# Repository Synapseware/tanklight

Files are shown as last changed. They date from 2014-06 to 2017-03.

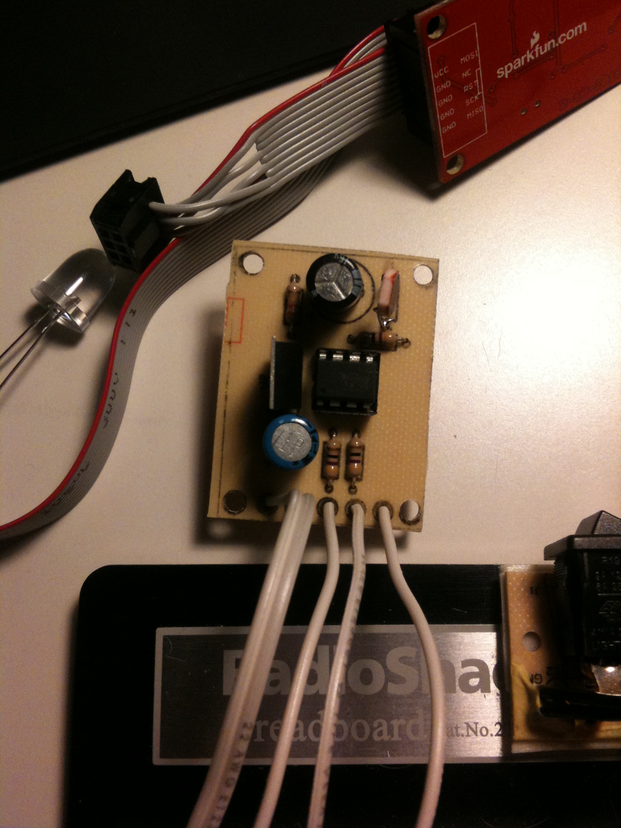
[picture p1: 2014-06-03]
media/IMG_3B10C66F-7ECF-4C1E-85A0-E6A24B57A7C3.JPG

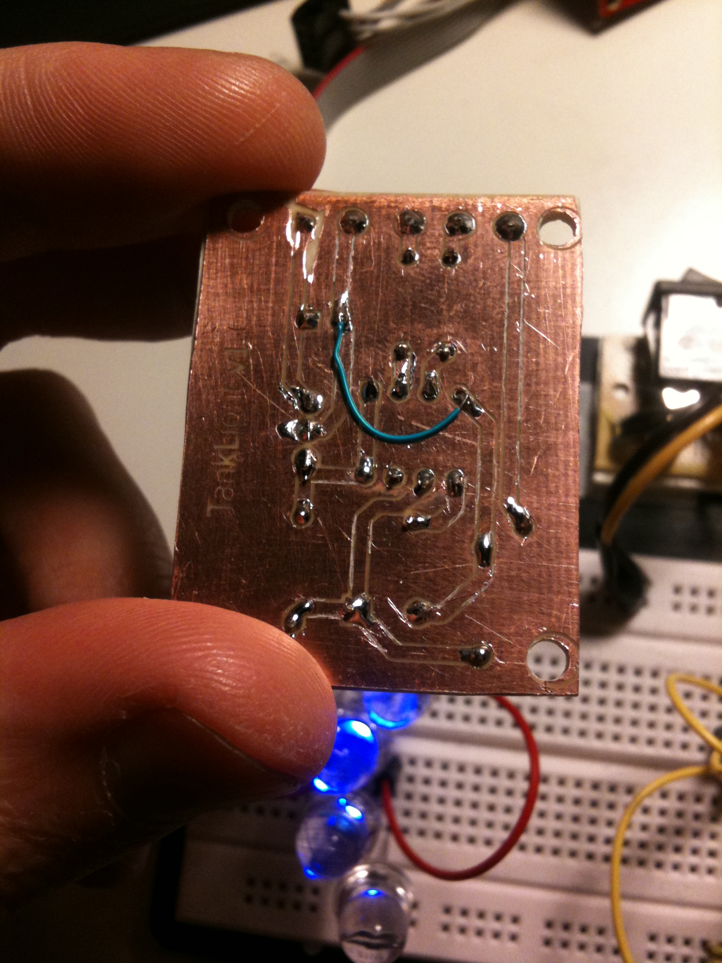
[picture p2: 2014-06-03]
media/IMG_438924C5-C81B-45E8-9A56-AECAA56EA485.JPG

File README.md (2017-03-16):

tanklights
==========

Tanklights is a fun project for adding moonlight lighting effects to a fish tank, or other environment where having an undulating lighting effect is desirable.  When properly laid out, the lighting is meant to be a rough simulation of what moonlight might look like under water.

The hardware/LEDs are wired up in a charlieplexed format.  Using just 3 pins of the micro controller (an Atmel ATTiny13), 6 LEDs can be individually controller.

The formula for the total number of LEDs is given by n^2-n, where n is the number of pins.  So, 3^2-3 = 6.

Read more about charlieplexing here: https://en.wikipedia.org/wiki/Charlieplexing

The lighting effects are accomplished by very fast switching of the LED matrix, so that persistence of vision plays a key role in the apparent light levels of the LEDs.

## building
The project has a simple Makefile.  It is currently configured to compiled under Linux only (but could be easily modified for other operating systems).  You will need to install AVRA, which is the open source equivalent of the Atmel AVR Assembler, avrasm.exe, that is included with AVR Studio for Windows.

### AVRA
Avra can also be installed easily on Linux:  `apt install -y avra` for Debian based systems.  The AVRA project home is here: http://avra.sourceforge.net/

### Atmel AVR Assembler
http://www.atmel.com/webdoc/avrassembler/index.html

### Other notes
The main idea with this project is not to build yet another LED blinking hello-world type of application, but is more a demonstration of what you can build using assembly and very lower powered micro-controllers.  Current code size is 640 bytes, or 320 words.  The timers on the ATTiny13 are used to advance or cycle through the lighting pattern, while the main charlieplexing display driver code is left to run at full speed.

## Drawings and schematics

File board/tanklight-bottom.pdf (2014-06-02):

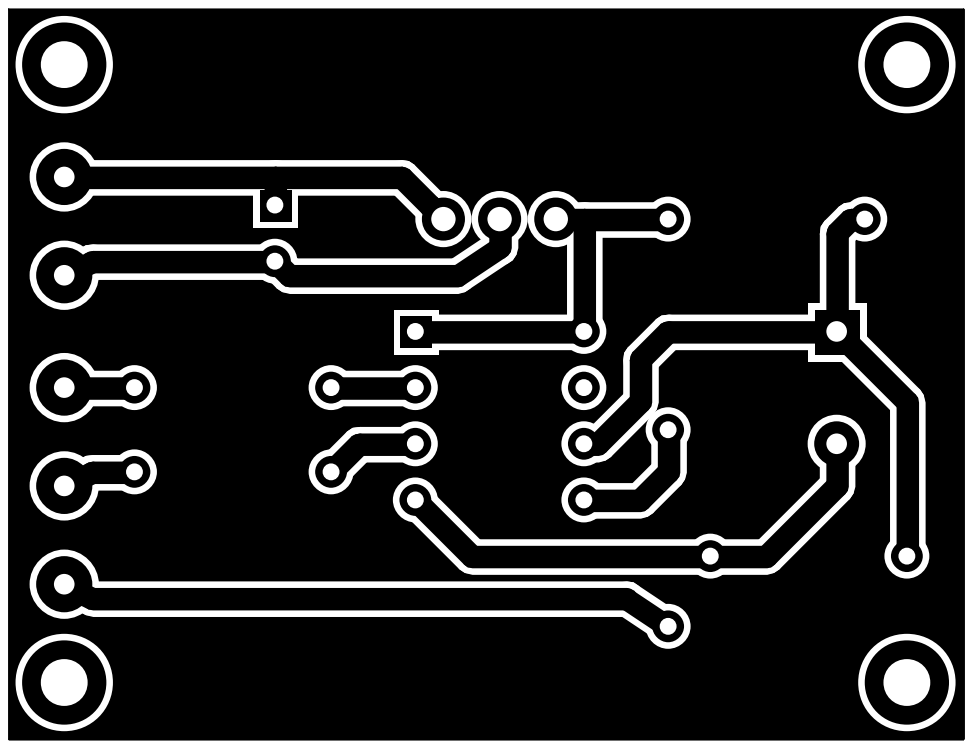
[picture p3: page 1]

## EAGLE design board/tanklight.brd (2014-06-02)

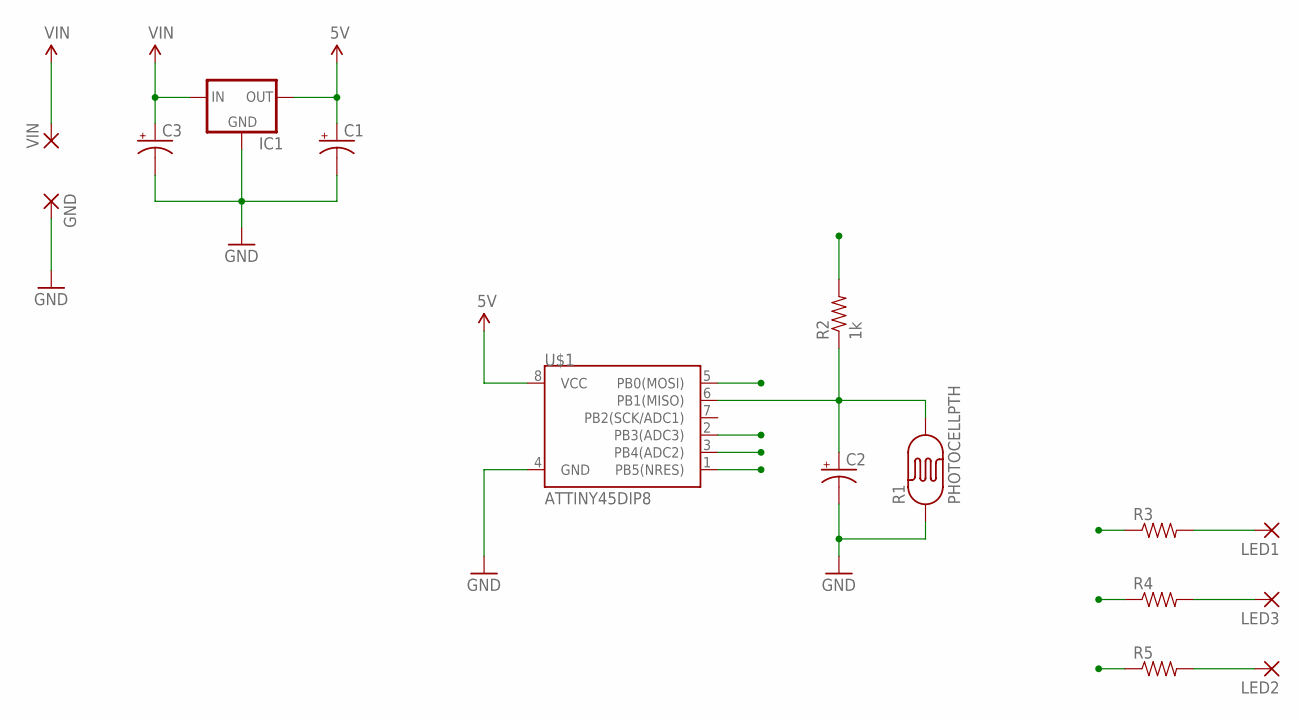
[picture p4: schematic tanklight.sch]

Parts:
C1, C3: CAP_POLPTH2; CPOL-RADIAL-10UF-25V
C2: CAP_POLPTH1; CPOL-RADIAL-100UF-25V
GND: 2,54/1,0
IC1: V_REG_78XXSINK; TO220-IGO
LED1, LED2, LED3: 2,54/1,0
R1: PHOTOCELLPTH; PHOTOCELL
R2: 1k; AXIAL-0.4
R3, R4, R5: RESISTORPTH-1/4W; AXIAL-0.4
U$1: ATTINY45DIP8; DIP08
VIN: 2,54/1,0

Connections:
5V: C1.1 (+), IC1.OUT, R2.P$2 (2), U$1.1 (PB5(NRES)), U$1.8 (VCC)
GND: C1.2 (-), C2.2 (-), C3.2 (-), GND.1, IC1.GND, R1.1, U$1.4 (GND)
LED1: R3.P$1 (1), U$1.5 (PB0(MOSI))
LED2: R5.P$1 (1), U$1.3 (PB4(ADC2))
LED3: R4.P$1 (1), U$1.2 (PB3(ADC3))
unnamed: C2.1 (+), R1.2, R2.P$1 (1), U$1.6 (PB1(MISO))
unnamed: LED1.1, R3.P$2 (2)
unnamed: LED3.1, R4.P$2 (2)
unnamed: LED2.1, R5.P$2 (2)
VIN: C3.1 (+), IC1.IN, VIN.1

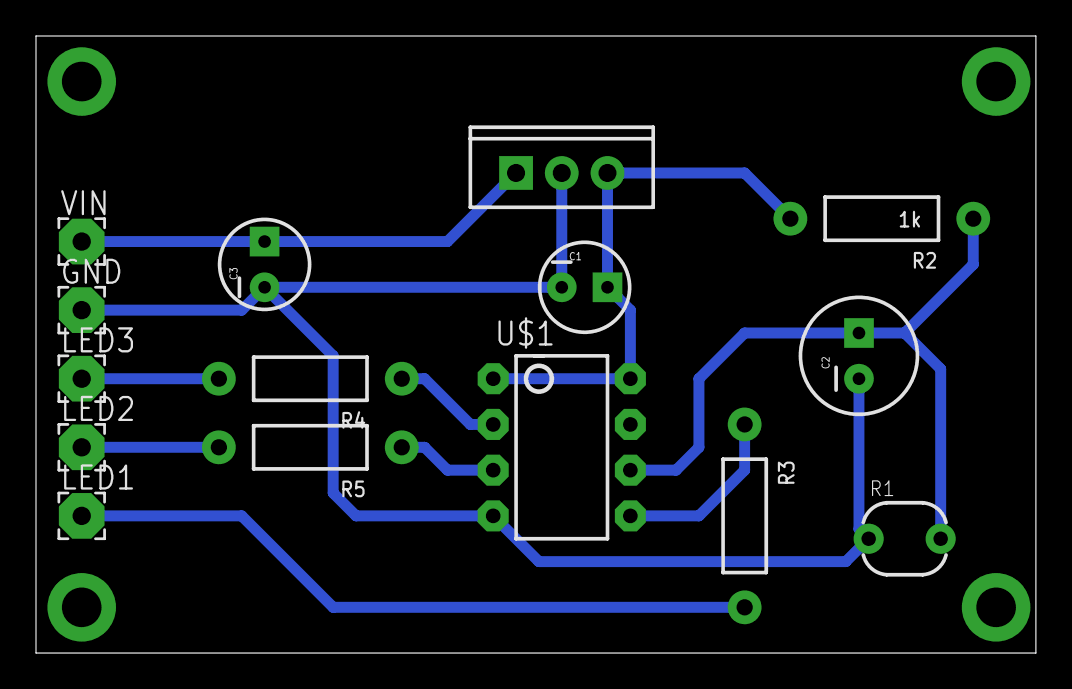
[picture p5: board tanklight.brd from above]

Board: 2 copper layers, 55.5 x 34.3 mm, 15 parts (0 on the bottom side), 10 nets.

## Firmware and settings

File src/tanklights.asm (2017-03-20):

;
; ********************************************
; Tank Light Project
; Drives 6 LEDs in a PWM/charlieplexed setup
; for gentle undulating night light.
; A photoresistor is connected across ANI1,
; so the light effect only runs when it's
; dark in the room.
; (C)2011 by Matthew Potter
; ********************************************

; Included header file for target AVR type
.NOLIST
.INCLUDE "tn13def.inc" ; Header for ATTINY13
.LIST
;
;
; ================================================================================================
;   R E G I S T E R   D E F I N I T I O N S
; ================================================================================================
.DEF	rmp				= r16
.DEF	rtmp			= r17
.DEF	rPWM_POS		= r18
.DEF	rACTIVE_LED		= r19
.DEF	rOFFSET			= r20
.DEF	rDELAY			= r21


; ================================================================================================
;	C O N S T A N T S
; ================================================================================================

; scan code status values
.EQU	PRIMARY_DELAY	= 180
.EQU	FIXED_DELAY		= 0
.EQU    TOTAL_CHANNELS  = 6
.EQU    LIGHT_TABLE_LEN = 252
.EQU    OFFSET_MULTIPLE = 42
.EQU	LED_PORT_MASK	= 0b11100110


; ================================================================================================
;	D A T A  S E G M E N T
; ================================================================================================
.DSEG
	on_values:	.BYTE	TOTAL_CHANNELS


; ================================================================================================
;   R E S E T   A N D   I N T   V E C T O R S
; ================================================================================================
;
.CSEG
.ORG $0000
	rjmp	Main ; Int vector 1 - Reset vector
	reti	; Int vector 2
	reti	; Int vector 3
	reti	; Int vector 4
	reti	; Int vector 5
	rjmp	ISR_AnalogComp_Handler ; Int vector 6
	rjmp	ISR_Timer0_CompareAHandler; Int vector 7
	reti	; Int vector 8
	reti	; Int vector 9
	reti	; Int vector 10


; ================================================================================================
; Timer0, compare A handler
; ================================================================================================
ISR_Timer0_CompareAHandler:
	push	rmp
	in		rmp, SREG
	push	rmp
	ldi		rmp, FIXED_DELAY
	tst		rmp
	breq	PC+0x04
	cpi		rDELAY, FIXED_DELAY					; check delay counter
	brlo	_to_ret1							; branch if we haven't reached our delay
	clr		rDELAY								; delay reached, clear delay
	inc		rOFFSET								; increment offset for next PWM pattern
	cpi		rOFFSET, LIGHT_TABLE_LEN			; check offset to make sure we are in range
	brlo	_to_ret2							; skip to return block if offset is OK
	clr		rOFFSET								; clear offset
	rjmp	_to_ret2							; skip to return block
_to_ret1:
	inc		rDELAY								; add 1 to delay counter
_to_ret2:
	pop		rmp
	out		SREG, rmp
	pop		rmp
	reti


; ================================================================================================
; Analog Comparator interrupt
; This handler is only enabled when the system is put into sleep mode.  The handler has to
; re-enable the main timer and start the lighting effects.
; ================================================================================================
ISR_AnalogComp_Handler:
	push	rmp
	in		rmp, SREG
	push	rmp

	in		rmp, ACSR
	andi	rmp, ~(1<<ACIE)						; disable interrupt handling
	out		ACSR, rmp
	in		rmp, TCCR0B							; enable timer0
	ori		rmp, (1<<CS02)
	ori		rmp, (1<<CS00)
	out		TCCR0B, rmp

	pop		rmp
	out		SREG, rmp
	pop		rmp
	reti


; ================================================================================================
; Main
; ================================================================================================
Main:
	ldi		rmp, LOW(RAMEND)					; Init LSB stack
	out		SPL, rmp
	rcall	Hardware_Init
	sei

Loop:
	wdr											; reset the watchdog timer
	;in		rmp, ACSR							; read ACSR register
	;sbrc	rmp, ACO							; skip if ACO is 0
	;rjmp	Halt								; when AC0 is 1, halt (too much light)
	rcall	PwmChnDrvr_Main						; invoke the channel driver
	ldi		r16, 0
	inc		r16
	cpi		r16, 0x10
	brlo	pc-2
	rjmp	Loop

Halt:
	cli
	rcall	PwmChnDrvr_Shutdown
	sbi		ACSR, ACI
	sbi		ACSR, ACIE
	in		rmp, TCCR0B							; disable timer
	andi	rmp, ~(1<<CS02)
	andi	rmp, ~(1<<CS00)
	out		TCCR0B, rmp
	sei
	sleep										; go to sleep
	rjmp	Loop


; ================================================================================================
; Initialize hardware (timers, ports, etc)
; ================================================================================================
Hardware_Init:
	; setup special registers
	clr		rPWM_POS
	clr		rACTIVE_LED

	; setup timer0
	ldi 	rmp, 0								; Normal mode
	out 	TCCR0A, rmp
	ldi 	rmp, (1<<CS02) | (1<<CS00)			; CLK/1024
	out 	TCCR0B, rmp
	ldi		rmp, PRIMARY_DELAY
	out		OCR0A, rmp
	in		rmp, TIMSK0							; enable compare-A interrupt
	ori		rmp, (1<<OCIE0A)
	out		TIMSK0, rmp

	; setup analog comparator
	cbi		ADCSRA, ADEN						; disable a/d converter
	cbi		ACSR, ACD							; enable analog comparator
	sbi		ACSR, ACBG							; use band-gap (1.1v ref)
	cbi		DDRB, PORTB1						; set compare input pin as input
	sbi		DIDR0, AIN1D						; disable digital input on AIN1

	; setup sleep mode (idle only)
	in		rmp, MCUCR
	andi	rmp, ~(1<<SM1)						; set SM1 to 0
	andi	rmp, ~(1<<SM0)						; set SM0 to 0
	ori		rmp, (1<<SE)						; set SE to 1
	out		MCUCR, rmp

	; clear the PWM channel data
	rcall	PwmChnDrvr_Clear

	ret


; ================================================================================================
;	B E G I N  A L L  T A B L E  S T O R A G E
; ================================================================================================
;								001          010          010          100          100          001
LED_PORT_VALUES:		.db		0b00000001,  0b00001000,  0b00001000,  0b00010000,  0b00010000,  0b00000001
;								011          110          011          110			101          101
LED_DDRX_VALUES:		.db		0b00001001,  0b00011000,  0b00001001,  0b00011000,  0b00010001,  0b00010001
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

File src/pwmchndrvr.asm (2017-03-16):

; ================================================================================================
; PWM_Channel_Driver
; Runs the PWM channels
; First portion always turns off all LEDs and turns on the active LED
; If we've completed a full LED refresh, then the PWM value data is updated.
; Uses:
;	X, Z, rmp, rtmp
; To invoke:
;	Registers:
;		rACTIVE_LED
;		rPWM_POS
;	Constants:
;		TOTAL_CHANNELS	(8bit)
;	Data:
;		on_values			(8bit value table, SRAM, element count = TOTAL_CHANNELS)
;		BRIGHTNESS_DATA		(8bit value table, PGRM, element count = TOTAL_CHANNELS)
;		LED_PORT_VALUES		(8bit value table, PGRM, element count = TOTAL_CHANNELS)
;		LED_DDRX_VALUES		(8bit value table, PGRM, element count = TOTAL_CHANNELS)
; ================================================================================================
PwmChnDrvr_Main:
		rcall	PwmChnDrvr_Shutdown

		; Check the active LED channel against the total channels
		; and only process PWM data if we've done a full refresh
		cpi		rACTIVE_LED, TOTAL_CHANNELS
		brlo	_pcd_activate_channel
		clr		rACTIVE_LED

		; Since we completed a full LED refresh,
		; decay or reload the PWM values table
		inc		rPWM_POS
		cpi		rPWM_POS, 0							; if 0, then reload PWM table
		breq	_pcd_seed							; rPWM_POS = 0, reload
		rcall	PwmChnDrvr_decay					; rPWM_POS != 0, so decay first
		rjmp	_pcd_activate_channel
	_pcd_seed:
		rcall	PwmChnDrvr_Seed						; rPWM_POS is zero, so reload the data

	_pcd_activate_channel:
		; First, turn on the active LED
		; If the SRAM segment @ active_led index > 0, then turn on that LED
		ldi		XH, HIGH(on_values)
		ldi		XL, LOW(on_values)
		clr		rtmp
		add		XL, rACTIVE_LED
		adc		XH, rtmp
		ld		rtmp, X								; load current on_value
		tst		rtmp
		breq	_pcd_activate_next
		ldi		ZH, HIGH(2*LED_PORT_VALUES)
		ldi		ZL, LOW(2*LED_PORT_VALUES)			; load PORT pointer
		clr		rtmp
		add		ZL, rACTIVE_LED						; add active LED offset
		adc		ZH, rtmp
		lpm		rtmp, Z								; load port value
		in		rmp, PORTB
		or		rtmp, rmp
		out		PORTB, rtmp
		ldi		ZH, HIGH(2*LED_DDRX_VALUES)
		ldi		ZL, LOW(2*LED_DDRX_VALUES)			; load DDRX pointer
		clr		rtmp
		add		ZL, rACTIVE_LED						; add active LED offset
		adc		ZH, rtmp
		lpm		rtmp, Z								; load ddr value
		in		rmp, DDRB
		or		rtmp, rmp
		out		DDRB, rtmp

	_pcd_activate_next:
		; Move to the next active LED.
		; If we are done with all active LEDs, change our PWM counter	
		inc		rACTIVE_LED
		ret


; ================================================================================================
; PwmChnDrvr_Shutdown
;	Shut down all LED output
; ================================================================================================
PwmChnDrvr_Shutdown:
		in		rmp, DDRB
		andi	rmp, LED_PORT_MASK
		out		DDRB, rmp
		in		rmp, PORTB
		andi	rmp, LED_PORT_MASK
		out		PORTB, rmp
		ret


; ================================================================================================
;	Clears the PWM channel data by writing 0's to all the channel values.
;	Uses:
;		rmp, rtmp, X
; ================================================================================================
PwmChnDrvr_Clear:
		ldi		XH, HIGH(on_values)
		ldi		XL, LOW(on_values)
		clr		rmp
		clr		rtmp
	_pcd_clr_loop:
		st		X+, rtmp
		inc		rmp
		cpi		rmp, TOTAL_CHANNELS
		brlo	_pcd_clr_loop
		ret


; ================================================================================================
;	Seeds the PWM channel data by copying values from the main brightness table into the channel
;	data buffer.
;	Uses:
;		rmp, rtmp, X, Z, r22, r23
;	Requires:
;		on_values
;		rOFFSET
;		TOTAL_CHANNELS
;		BRIGHTNESS_DATA
; ================================================================================================
PwmChnDrvr_Seed:
		ldi		XH, HIGH(on_values)
		ldi		XL, LOW(on_values)
		clr		rmp
	_pcd_seed_loop:
		ldi		ZH, HIGH(2*TABLE_MULT_OFFSET)		; get our offset...
		ldi		ZL, LOW(2*TABLE_MULT_OFFSET)
		add		ZL, rmp								; add loop index to the offset table address
		brcc	PC+2
		inc		ZH									; add 1 to MSB register if overflow from previous addition
		ldi		YH, 0								; load table offset into Y register
		lpm		YL, Z
		add		YL, rOFFSET							; add our offset
		brcc	PC+2
		inc		YH
		ldi		ZH, 0								; load our 16 bit compare value
		ldi		ZL, LIGHT_TABLE_LEN
		cp		YL, ZL								; compare 16 bit registers
		cpc		YH, ZH
		brlo	PC+4
		sub		YL, ZL								; subtract if over limit...
		sbc		YH, ZH
	_pcd_seed_1:
		; Copy brightness values from table to SRAM segment
		ldi		ZH, HIGH(2*BRIGHTNESS_DATA)
		ldi		ZL, LOW(2*BRIGHTNESS_DATA)			; Z is pointer to program memory
		add		ZL, YL								; add offset from rtmp to Z
		brcc	PC+2								; skip over the next instruction (careful with the offset!)
		inc		ZH
		lpm		rtmp, Z								; load the brightness table value
		st		X+, rtmp							; store the brightness table value
		inc		rmp									; increment loop value
		cpi		rmp, TOTAL_CHANNELS
		brlo	_pcd_seed_loop						; continue loop if not done
		ret


; ================================================================================================
;	Decays the PWM channel data
;	Uses:
;		rmp, rtmp, X
; ================================================================================================
PwmChnDrvr_decay:
		ldi		XH, HIGH(on_values)
		ldi		XL, LOW(on_values)
		clr		rmp
	_pcd_decay_loop:
		ld		rtmp, X
		cpi		rtmp, 0
		breq	PC+2
		dec		rtmp
		st		X+, rtmp
		inc		rmp									; increment loop value
		cpi		rmp, TOTAL_CHANNELS
		brlo	_pcd_decay_loop						; continue loop if not done
		ret

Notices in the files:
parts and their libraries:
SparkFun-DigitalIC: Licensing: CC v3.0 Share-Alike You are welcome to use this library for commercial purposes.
